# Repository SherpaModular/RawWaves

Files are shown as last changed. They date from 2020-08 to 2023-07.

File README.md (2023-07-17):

## Raw Waves v2

Raw Waves v2 is a sample player that functions much like a live radio. Audio sample files may be placed on a MicroSD card, and arranged into "banks" (like channels) which you may select either manually through the panel knobs, or via CV. File formats supported include RAW and WAV files.

The module is functionally identical to the popular "Raw Waves" module, and its predecessor, "Radio Music" by Tom Whitwell of Music Thing Modular. These previous modules are no longer available, having been built upon the now-discontinued Teensy 3 microcontroller.

Raw Waves v2 has been completely redesigned to use the Teensy 4 platform. Because the module uses the Teensy 4 microcontroller, the "Raw Waves v2" will not be compatible with other alternative firmware made for Radio Music (e.g. 'Chord Organ').

Raw Waves v2 still supports all of the settings in the SETTINGS.TXT file that you came to know and love in the earlier models. If you haven't played with the settings, you really should!

#### Specifications
Audio output: 16-bit audio output, with hardware anti-alias filtering.
Dimensions: 4 hp, 21mm deep.
Power specifications: Requires +12v (at 100 mA) and -12v (at 10 mA). The module features several protections against accidental reverse power connection: First, a keyed 10-pin Eurorack standard connector, second, automatically resetting fuses, and thirdly, protection diodes.
CV Inputs are designed for 0-5v, with reasonable over/undervoltage protection built-in.

#### Compiling the code
My preference is to use Visual Studio Code:
1. Install the Microsoft "Arduino for Visual Studio Code" extension
2. Add the Teensy packages. You can accomplish this in the "Arduino for Visual Studio Code" extension settings by adding the URL https://www.pjrc.com/teensy/package_teensy_index.json to the "Arduino: Additional Urls, Additional URLs for 3rd party packages." setting.
3. The following file contents, placed into the repo under the filename .vscode\arduino.json helps with other details:
```
{
    "sketch": "Software\\RawWavesV2\\RawWavesV2.ino",
    "configuration": "usb=serial,speed=600,opt=o2std,keys=en-us",
    "board": "teensy:avr:teensy40",
    "output": "ArduinoOutput\\RawWavesV2",
    "port": "COM3"
}
```
4. In VS Code, activate the Command Palette (typically by pressing F1), and choose "Ardunio: Verify".
5. If all codes well, the compiled output should appear in the repo directory, under ArduinoOutput\RawWavesV2

#### License  
Raw Waves is Open Hardware. It is a derivate work of ["Radio Music", by Tom Whitwell](https://github.com/TomWhitwell/RadioMusic). 
All hardware and software design in this project is Creative Commons licensed by Jim Mulvey: [CC-BY-SA: Attribution / ShareAlike](https://creativecommons.org/licenses/by-sa/3.0/)
If you use any work in this project, you should credit Tom Whitwell and me, and you must republish any changes you make under the same license.
This license does permit commercial use of these designs, but consider getting in touch before selling anything.
This project includes work from the [Teensy](https://www.pjrc.com/teensy/) project, which is not covered by this license.

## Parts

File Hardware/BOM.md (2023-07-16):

| Designator | Footprint | Quantity | Value |
| --- | --- | --- | --- |
| RV1 | Alpha9mmPot | 1 | B50k |
| LED1,LED2,LED3,LED4,RESET_LED1 | LED_D3.0mm | 5 | 3mm LED, high lumen |
| J3 | YAMAICHI_MICROSD_VERTICAL | 1 | Micro_SD_Card |
| J1,J2,J5,J6 | PJ301M-12_Compact | 4 | Thonkiconn |
| SW1 | Push_E-Switch_KS01Q01 | 1 | SW_DIP_x01 |
| RV2 | Alpha9mmPot | 1 | B50k |
| R2,R3,R4,R5,R10,R14,R15 | R_0603_1608Metric | 7 | 10k, 1% |
| C3,C9,C4 | CP_Elec_4x5.4 | 3 | 10uF, 25v |
| C1,C11,C2,C10,C7,C5 | C_0603_1608Metric | 6 | 100nF, 25v |
| R16,R19,R8,R12,R1,R20 | R_0603_1608Metric | 6 | 100k, 1% |
| R17,R18 | R_0603_1608Metric | 2 | 200k, 1% |
| D8,D7 | D_SOD-323 | 2 | 1N5819 |
| U1 | Teensy4.0 | 1 | Teensy4.0 |
| R13 | R_0603_1608Metric | 1 | 1k, 1% |
| F2,F1 | R_0805_2012Metric | 2 | Polyfuse_Small |
| U2 | SOIC-8_3.9x4.9mm_P1.27mm  | 1 | PT8211 |
| R11 | R_0603_1608Metric | 1 | 120k, 1% |
| U5 | SOIC-8_3.9x4.9mm_P1.27mm  | 1 | MCP6002 |
| R7,R6 | R_0603_1608Metric | 2 | 5.6k, 1% |
| U4 | SOT-223-3_TabPin2 | 1 | LM1117MP-5.0 |
| Q1 | SOT-23 | 1 | MMBT3904 |
| U6 | SOIC-8_3.9x4.9mm_P1.27mm  | 1 | TL072 |
| C8,C6 | C_0603_1608Metric | 2 | 1nF, 25v |
| R9 | R_0603_1608Metric | 1 | 330k, 1% |
| J4 | Eurorack_power_header | 1 | EURO_PWR_2x5 |

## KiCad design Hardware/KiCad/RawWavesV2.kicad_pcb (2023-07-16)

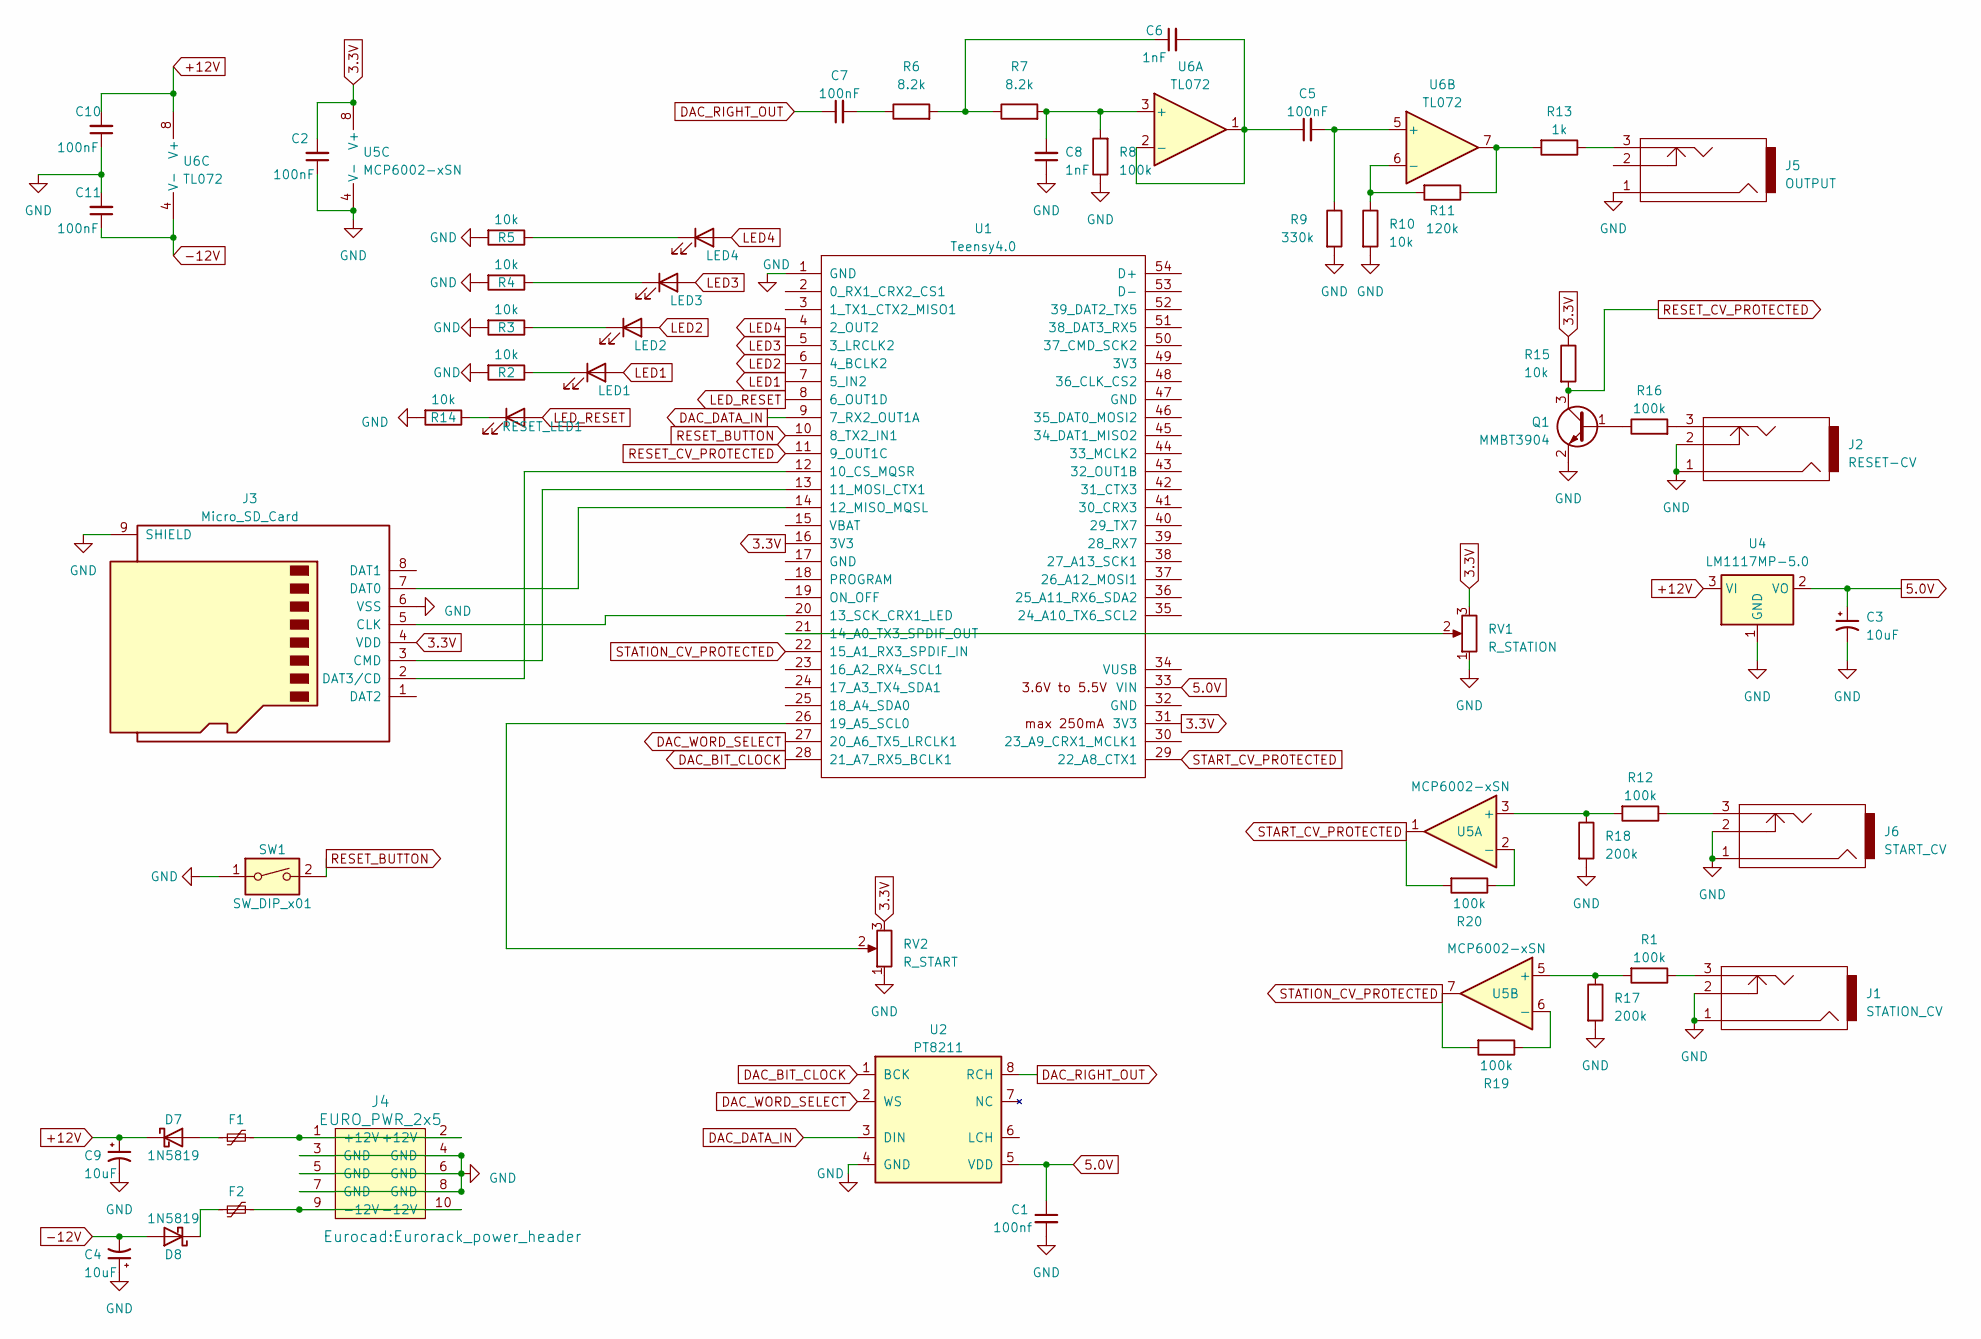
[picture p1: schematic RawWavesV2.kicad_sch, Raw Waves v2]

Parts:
C1: 100nf; C_0603_1608Metric
C2, C5, C7, C10, C11: 100nF; C_0603_1608Metric
C3, C4, C9: 10uF; CP_Elec_4x5.4
C6, C8: 1nF; C_0603_1608Metric
D7, D8: 1N5819; D_SOD-323
F1, F2: Polyfuse_Small; R_0805_2012Metric
J1: STATION_CV; PJ301M-12_Compact
J2: RESET-CV; PJ301M-12_Compact
J3: Micro_SD_Card; YAMAICHI_MICROSD_VERTICAL
J4: EURO_PWR_2x5; Eurorack_power_header
J5: OUTPUT; PJ301M-12_Compact
J6: START_CV; PJ301M-12_Compact
LED1: LED1; LED_D3.0mm
LED2: LED2; LED_D3.0mm
LED3: LED3; LED_D3.0mm
LED4: LED4; LED_D3.0mm
Q1: MMBT3904; SOT-23
R1, R8, R12, R16, R19, R20: 100k; R_0603_1608Metric
R2, R3, R4, R5, R10, R14, R15: 10k; R_0603_1608Metric
R6, R7: 8.2k; R_0603_1608Metric
R9: 330k; R_0603_1608Metric
R11: 120k; R_0603_1608Metric
R13: 1k; R_0603_1608Metric
R17, R18: 200k; R_0603_1608Metric
RESET_LED1: RESET_LED; LED_D3.0mm
RV1: R_STATION; Alpha9mmPot
RV2: R_START; Alpha9mmPot
SW1: SW_DIP_x01; Push_E-Switch_KS01Q01
U1: Teensy4.0; Teensy4.0-RawWavesV2
U2: PT8211; SOIC-8_3.9x4.9mm_P1.27mm
U4: LM1117MP-5.0; SOT-223-3_TabPin2
U5: MCP6002-xSN; SOIC-8_3.9x4.9mm_P1.27mm
U6: TL072; SOIC-8_3.9x4.9mm_P1.27mm

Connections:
3.3V: C2.2, J3.4 (VDD), R15.1, RV1.3, RV2.3, U1.16 (3V3), U1.31 (3V3), U5.8 (V+)
5.0V: C1.1, C3.1, U1.33 (VIN), U2.5 (VDD), U4.2 (VO)
+12V: C9.1, C10.2, D7.1 (K), U4.3 (VI), U6.8 (V+)
-12V: C4.2, C11.1, D8.2 (A), U6.4 (V-)
DAC_BIT_CLOCK: U1.28 (21_A7_RX5_BCLK1), U2.1 (BCK)
DAC_DATA_IN: U1.9 (7_RX2_OUT1A), U2.3 (DIN)
DAC_RIGHT_OUT: C7.1, U2.8 (RCH)
DAC_WORD_SELECT: U1.27 (20_A6_TX5_LRCLK1), U2.2 (WS)
GND: C1.2, C2.1, C3.2, C4.1, C8.1, C9.2, C10.1, C11.2, J1.1, J1.2, J2.1, J2.2, J3.6 (VSS), J3.9 (SHIELD), J4.3 (GND), J4.4 (GND), J4.5 (GND), J4.6 (GND), J4.7 (GND), J4.8 (GND), J5.1, J6.1, J6.2, Q1.2 (E), R2.2, R3.2, R4.2, R5.2, R8.1, R9.2, R10.2, R14.2, R17.2, R18.2, RV1.1, RV2.1, SW1.1, U1.1 (GND), U2.4 (GND), U4.1 (GND), U5.4 (V-)
LED1: LED1.2 (A), U1.7 (5_IN2)
LED2: LED2.2 (A), U1.6 (4_BCLK2)
LED3: LED3.2 (A), U1.5 (3_LRCLK2)
LED4: LED4.2 (A), U1.4 (2_OUT2)
LED_RESET: RESET_LED1.2 (A), U1.8 (6_OUT1D)
unnamed: C6.1, R6.2, R7.1
unnamed: C7.2, R6.1
unnamed: D7.2 (A), F1.1
unnamed: D8.1 (K), F2.1
unnamed: F1.2, J4.1 (+12V), J4.2 (+12V)
unnamed: F2.2, J4.9 (-12V), J4.10 (-12V)
unnamed: J1.3, R1.1
unnamed: J2.3, R16.2
unnamed: J3.5 (CLK), U1.20 (13_SCK_CRX1_LED)
unnamed: J3.3 (CMD), U1.13 (11_MOSI_CTX1)
unnamed: J3.7 (DAT0), U1.14 (12_MISO_MQSL)
unnamed: J3.2 (DAT3/CD), U1.12 (10_CS_MQSR)
unnamed: J5.3, R13.1
unnamed: J6.3, R12.1
unnamed: LED1.1 (K), R2.1
unnamed: LED2.1 (K), R3.1
unnamed: LED3.1 (K), R4.1
unnamed: LED4.1 (K), R5.1
unnamed: Q1.1 (B), R16.1
unnamed: R11.1, R13.2, U6.7
unnamed: R14.1, RESET_LED1.1 (K)
unnamed: RV1.2, U1.21 (14_A0_TX3_SPDIF_OUT)
unnamed: RV2.2, U1.26 (19_A5_SCL0)
unnamed: R12.2, R18.1, U5.3 (+)
unnamed: R20.1, U5.2 (-)
unnamed: R1.2, R17.1, U5.5 (+)
unnamed: R19.1, U5.6 (-)
unnamed: C8.2, R7.2, R8.2, U6.3 (+)
unnamed: C5.1, C6.2, U6.1, U6.2 (-)
unnamed: C5.2, R9.1, U6.5 (+)
unnamed: R10.1, R11.2, U6.6 (-)
RESET_BUTTON: SW1.2, U1.10 (8_TX2_IN1)
RESET_CV_PROTECTED: Q1.3 (C), R15.2, U1.11 (9_OUT1C)
START_CV_PROTECTED: R20.2, U1.29 (22_A8_CTX1), U5.1
STATION_CV_PROTECTED: R19.2, U1.22 (15_A1_RX3_SPDIF_IN), U5.7

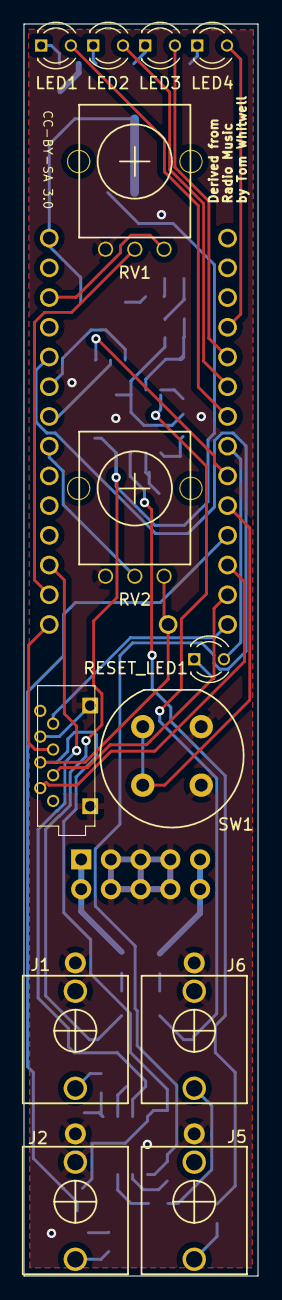
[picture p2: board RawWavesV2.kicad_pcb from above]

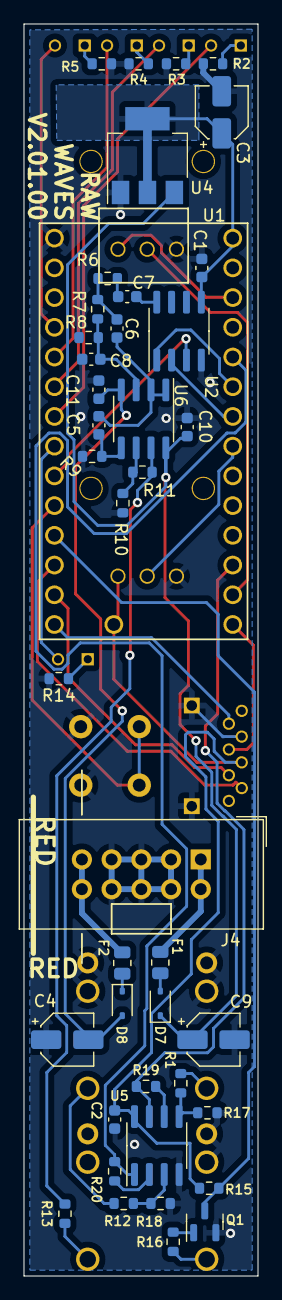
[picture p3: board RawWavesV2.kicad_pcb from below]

Board: 2 copper layers, 20.0 x 107.0 mm, 55 parts (42 on the bottom side), 49 nets.

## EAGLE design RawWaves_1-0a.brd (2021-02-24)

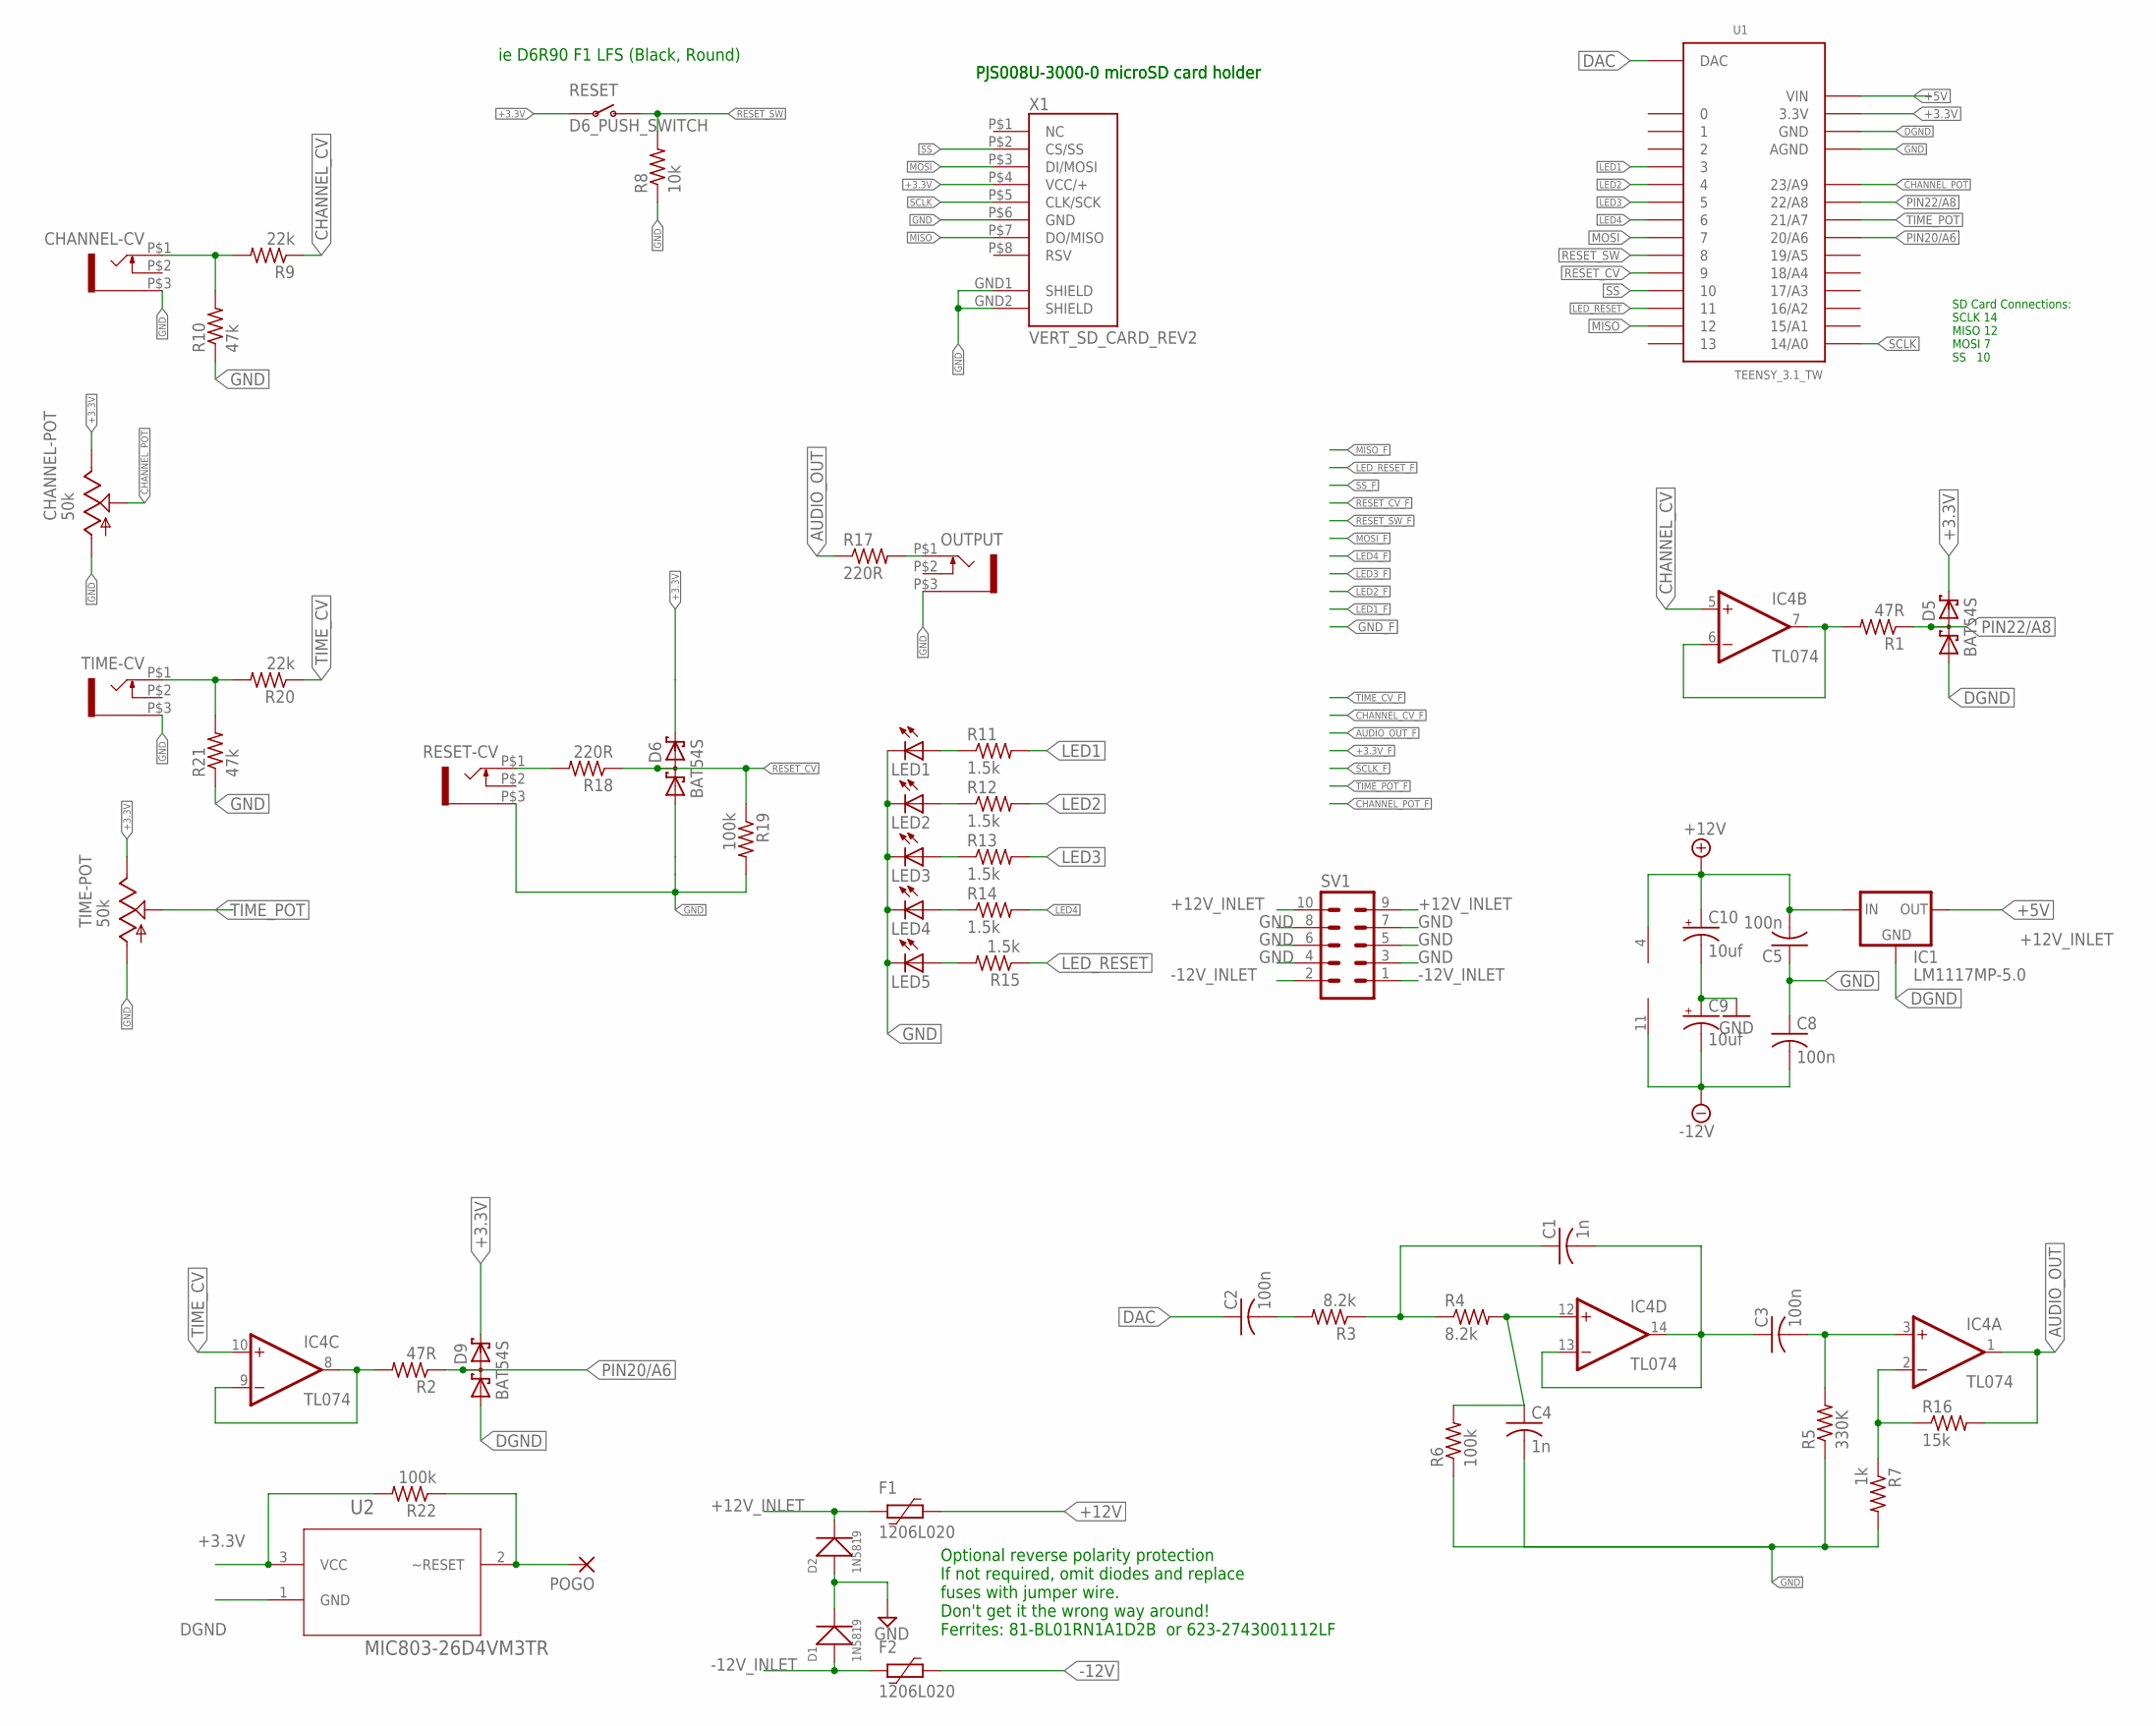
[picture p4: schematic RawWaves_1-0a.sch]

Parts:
C1, C4: 1n; C0805
C2, C3, C5, C8: 100n; C0805
C9, C10: 10uf; PANASONIC_B
CHANNEL-CV: WQP-PJ301M-12_JACK
CHANNEL-POT: 50k; EVUF
D1, D2: 1N5819; SOD-123
D5, D6, D9: BAT54S; SOT23
F1, F2: 1206L020; 1206L
IC1: LM1117MP-5.0; SOT223
IC4: TL074; SO14
LED1, LED2, LED3, LED4, LED5: LED3MM
OUTPUT: WQP-PJ301M-12_JACK
POGO: 1,6/0,8
R1, R2: 47R; R0805
R3, R4: 8.2k; R0805
R5: 330K; R0805
R6, R19, R22: 100k; R0805
R7: 1k; R0805
R8: 10k; R0805
R9, R20: 22k; R0805
R10, R21: 47k; R0805
R11, R12, R13, R14, R15: 1.5k; R0805
R16: 15k; R0805
R17, R18: 220R; R0805
RESET: D6_PUSH_SWITCH; D6_BUTTON_RND
RESET-CV: WQP-PJ301M-12_JACK
SV1: 10_PIN_HEADER; MA05-2
TIME-CV: WQP-PJ301M-12_JACK
TIME-POT: 50k; EVUF
U1: TEENSY_3.1_TW
U2: MIC803-26D4VM3TR; SOT95P232X110-3N
X1: VERT_SD_CARD_REV2; VERT_MICROSD_REV2

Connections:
+3.3V: CHANNEL-POT.3 (E), D5.2 (C2), D6.2 (C2), D9.2 (C2), R22.2, RESET.P$3, RESET.P$4, TIME-POT.3 (E), U1.3.3V, U2.3 (VCC), X1.P$4 (VCC/+)
+5V: IC1.2 (OUT), IC1.4 (OUT), U1.VIN
+12V: C5.2, C10.+, F1.1, IC1.3 (IN), IC4.4 (V+)
+12V_INLET: D2.-, F1.2, SV1.9, SV1.10
-12V: C8.2, C9.-, F2.1, IC4.11 (V-)
-12V_INLET: D1.+, F2.2, SV1.1, SV1.2
AUDIO_OUT: IC4.1 (OUT), R16.2, R17.1
CHANNEL_CV: IC4.5 (+IN), R9.1
CHANNEL_POT: CHANNEL-POT.2 (S), U1.23/A9
DAC: C2.1, U1.DAC
DGND: D5.1 (A1), D9.1 (A1), IC1.1 (GND), U1.GND, U2.1 (GND)
GND: C4.2, C5.1, C8.1, C9.+, C10.-, CHANNEL-CV.P$3 (1), CHANNEL-POT.1 (A), D1.-, D2.+, D6.1 (A1), LED1.K (C), LED2.K (C), LED3.K (C), LED4.K (C), LED5.K (C), OUTPUT.P$3 (1), R5.1, R6.1, R7.2, R8.1, R10.1, R19.2, R21.1, RESET-CV.P$3 (1), SV1.3, SV1.4, SV1.5, SV1.6, SV1.7, SV1.8, TIME-CV.P$3 (1), TIME-POT.1 (A), U1.AGND, X1.GND1 (SHIELD), X1.GND2 (SHIELD), X1.P$6 (GND)
LED1: R11.2, U1.3
LED2: R12.2, U1.4
LED3: R13.2, U1.5
LED4: R14.2, U1.6
LED_RESET: R15.1, U1.11
MISO: U1.12, X1.P$7 (DO/MISO)
MOSI: U1.7, X1.P$3 (DI/MOSI)
unnamed: IC4.6 (-IN), IC4.7 (OUT), R1.2
unnamed: C4.1, IC4.12 (+IN), R4.2, R6.2
unnamed: OUTPUT.P$1 (2), R17.2
unnamed: C1.1, R3.1, R4.1
unnamed: C1.2, C3.1, IC4.13 (-IN), IC4.14 (OUT)
unnamed: C3.2, IC4.3 (+IN), R5.2
unnamed: IC4.2 (-IN), R7.1, R16.1
unnamed: IC4.8 (OUT), IC4.9 (-IN), R2.2
unnamed: CHANNEL-CV.P$1 (2), R9.2, R10.2
unnamed: C2.2, R3.2
unnamed: LED2.A, R12.1
unnamed: LED4.A, R14.1
unnamed: LED3.A, R13.1
unnamed: R18.2, RESET-CV.P$1 (2)
unnamed: LED1.A, R11.1
unnamed: LED5.A, R15.2
unnamed: POGO.1, R22.1, U2.2 (~RESET)
PIN20/A6: D9.3 (C1A2), R2.1, U1.20/A6
PIN22/A8: D5.3 (C1A2), R1.1, U1.22/A8
RESET_CV: D6.3 (C1A2), R18.1, R19.1, U1.9
RESET_SW: R8.2, RESET.P$1 (O), RESET.P$2 (O), U1.8
SCLK: U1.14/A0, X1.P$5 (CLK/SCK)
SS: U1.10, X1.P$2 (CS/SS)
TEMP: R20.2, R21.2, TIME-CV.P$1 (2)
TIME_CV: IC4.10 (+IN), R20.1
TIME_POT: TIME-POT.2 (S), U1.21/A7

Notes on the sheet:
ie D6R90 F1 LFS (Black, Round)
PJS008U-3000-0 microSD card holder
SD Card Connections: SCLK 14 MISO 12 MOSI 7 SS 10
Optional reverse polarity protection If not required, omit diodes and replace fuses with jumper wire. Don't get it the wrong way around! Ferrites: 81-BL01RN1A1D2B or 623-2743001112LF

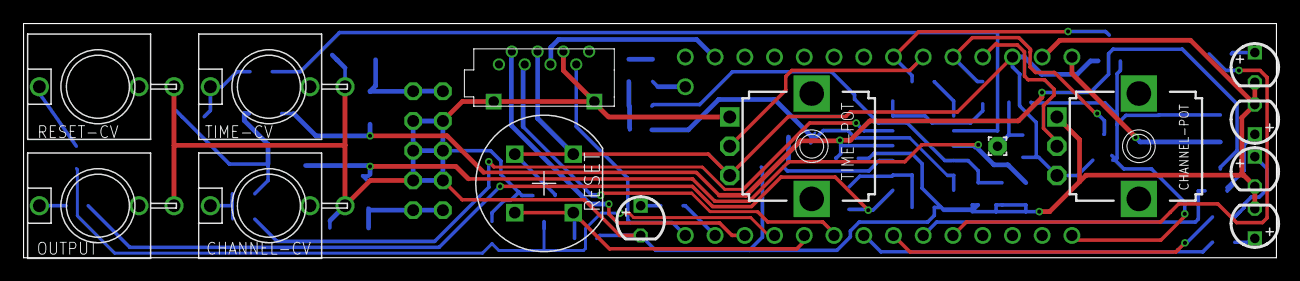
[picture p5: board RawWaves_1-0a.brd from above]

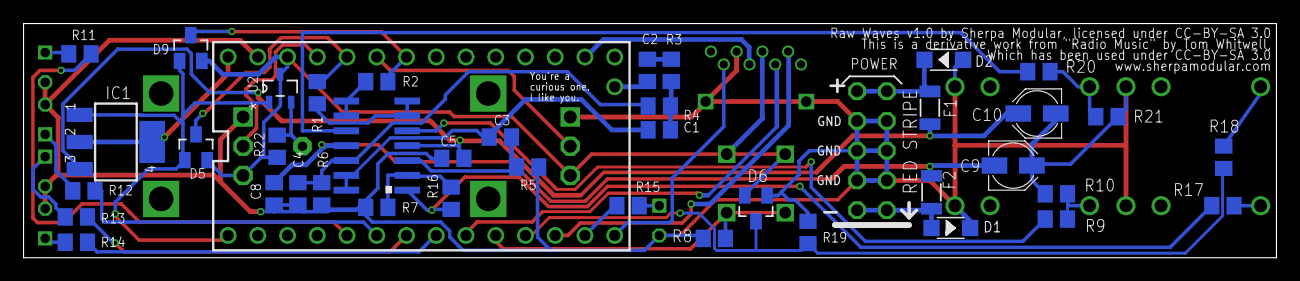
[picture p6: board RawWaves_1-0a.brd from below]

Board: 4 copper layers, 107.0 x 20.0 mm, 56 parts (42 on the bottom side), 45 nets.

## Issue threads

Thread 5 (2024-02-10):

No audio... modified versions of files?

doctea, 2024-02-10:
EDIT AGAIN: after enabling a lot of debug stuff to find out why the play position didn't seem to be updating, etc, and trying out the 'Blank' soundset rather than the other huge sound archives, I notice that amongst the bus noise I'm also hearing very faint bird song when the BIRDS clip is playing, while its powered from USB.  Connecting to eurorack and making sure to play that bank now works OK too.  So seems like I might be having some problems with the sound files in the archive (they seemed to be reporting a large filesize, but 0 length?  not sure).

Seems like probably nothing wrong with the software or hardware anyway, but I'll leave this here in case it helps anyone else when they're trying to find a solution to similar problem: make sure to connect over Eurorack 'cos the audio amplifier won't work when powered only from USB, and make sure the files work!

------

Hi!  Thanks for sharing this project.  I've built one, and it all appears to be working (LEDs light up, respond to knobs being turned and buttons pushed, enabling DEBUG shows files are being detected on the SD card, etc), but I get no sound at the output.  (Well, just bus noise if I turn the gain right up).

I noticed in the RawWavesV2.ino file this comment..

```
 NB: Compile using modified versions of:
 SD.cpp (found in the main Arduino package)
 play_sd_raw.cpp  - In Teensy Audio Library
 play_sc_raw.h    - In Teensy Audio Library
```

..but I couldn't see any modified files with those names in the repository.

Am I missing something about these files?  If necessary, could you please provide steps on what modifications are necessary?

And, could this be the reason I'm not getting any sound output?

Thanks!

EDIT: after a bit more poking around, it seems that this message about the modified versions may just be left over from the original Radio Music source, where it hadn't even been necessary there for quite a while either..?

Any other simple and obvious reasons why I might not be getting any audio output?

Closed 2024-02-11.

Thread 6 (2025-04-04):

'Button' does not name a type

jojo-monk, 2025-04-04:
Hello,

J'ai cette erreur à la compilation : 'Button' does not name a type

jojo-monk, 2025-04-05:
I fixed the bug with:
`Bounce2::Button resetButton;`
Instead of
`Button resetButton;`
in Interface.h

Coombsy87, 2025-07-31:
> I fixed the bug with: `Bounce2::Button resetButton;` Instead of `Button resetButton;` in Interface.h

Thank you for this!! Was doing my head in...

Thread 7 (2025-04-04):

click noise station potentiometer

jojo-monk, 2025-04-04:
When I turn the station potentiometer, we only hear clicks from the beginning until noon, we only hear the samples on the 2nd half of the potentiometer stroke (from 12h until the end).

jojo-monk, 2025-04-05:
Ok, the problem comes from macOS which creates hidden files. The teensy considers them as audio files.

Just delete the hidden files, and everything works.

jmulvey123, 2025-05-16:
Thanks @jojo-monk for creating the issue... and especially for coming back to tell us the cause!
Best, - Jim

Closed 2025-05-16.

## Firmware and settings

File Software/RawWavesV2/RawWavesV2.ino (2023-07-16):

/*
 RAW WAVES v2.0
 https://github.com/SherpaModular/RawWaves
 
 Teensy 4.0
 Audio out: PT8211 external DAC
 
 Bank Button: 2
 Bank LEDs 3,4,5,6
 Reset Button: 8
 Reset LED 2
 Reset CV input: 9
 Channel Pot: A9
 Channel CV: A8 // check
 Time Pot: A7
 Time CV: A6 // check

 SD Card Connections:
 SCK  13
 MISO 12
 MOSI 11
 SS   10
 
 NB: Compile using modified versions of: 
 SD.cpp (found in the main Arduino package) 
 play_sd_raw.cpp  - In Teensy Audio Library 
 play_sc_raw.h    - In Teensy Audio Library 

 */
#include <EEPROM.h>
#include <SPI.h>
#include <SD.h>
//#include <Wire.h>
#include "RawWaves.h"
#include "AudioSystemHelpers.h"
#include "Settings.h"
#include "LedControl.h"
#include "FileScanner.h"
		// which will bring:
		// #include "AudioFileInfo.h"
		// #include "WavHeaderReader.h"
		// #include "Settings.h"
#include "AudioEngine.h"
		// which will bring:
		// #include "SDPlayPCM.h"
		// #include "Settings.h"
#include "Interface.h"
		// which will bring:
		// #include "PlayState.h"
		// #include "Settings.h"
		// #include "AnalogInput.h"
#include "PlayState.h"

#ifdef DEBUG
#define D(x) x
#else
#define D(x)
#endif

#define EEPROM_BANK_SAVE_ADDRESS 0

#define FLASHTIME 	10  	// How long do LEDs flash for?
#define SD_CARD_CHECK_DELAY 20

// //////////
// TIMERS
// //////////

elapsedMillis resetLedTimer = 0;
elapsedMillis ledFlashTimer = 0;

elapsedMillis meterDisplayDelayTimer; // Counter to hide MeterDisplay after bank change
elapsedMillis peakDisplayTimer; // COUNTER FOR PEAK METER FRAMERATE


boolean bankChangeMode = false;
File settingsFile;

Settings settings("SETTINGS.TXT");
LedControl ledControl;
FileScanner fileScanner;
AudioEngine audioEngine;
Interface interface;
PlayState playState;

int NO_FILES = 0;
uint8_t noFilesLedIndex = 0;

uint8_t rebootCounter = 0;

void setup() {

#ifdef DEBUG_STARTUP // Pauses module startup until serial connection is made
	while( !Serial );
	Serial.println("Starting");
#endif // DEBUG_STARTUP

	ledControl.init();
	ledControl.single(playState.bank);

	// SD CARD SETTINGS FOR AUDIO SHIELD
    SPI.setMOSI(11); // pin for MOSI, was 7 in Teensy 3.2 version
    SPI.setSCK(13); // pin for SCK, was 14 in Teensy 3.2 version

	boolean hasSD = openSDCard();
	if(!hasSD) {
		Serial.println("Rebooting");
		reBoot(0);
	}

	settings.init();

	File root = SD.open("/");
	fileScanner.scan(&root, settings);

	getSavedBankPosition();

	audioEngine.init(settings);

	int numFiles = 0;
	for(int i=0;i<=fileScanner.lastBankIndex;i++) {
		numFiles += fileScanner.numFilesInBank[i];
	}
	D(Serial.print("File Count ");Serial.println(numFiles););

	if(numFiles == 0) {
		NO_FILES = 1;
		D(Serial.println("No files"););
		ledFlashTimer = 0;
	} else if(fileScanner.numFilesInBank[playState.bank] == 0) {
		D(Serial.println("Empty bank"););
		while(fileScanner.numFilesInBank[playState.bank] == 0) {
			playState.bank++;
			if(playState.bank == fileScanner.lastBankIndex) {
				playState.bank = 0;
			}
		}
		D(Serial.print("Set bank to ");Serial.println(playState.bank););
	}

	interface.init(fileScanner.fileInfos[playState.bank][0].size, fileScanner.numFilesInBank[playState.bank], settings, &playState);

	D(Serial.println("--READY--"););
}

void getSavedBankPosition() {
	// CHECK FOR SAVED BANK POSITION
	int a = 0;
	a = EEPROM.read(EEPROM_BANK_SAVE_ADDRESS);
	if (a >= 0 && a <= fileScanner.lastBankIndex) {
		D(
			Serial.print("Using bank from EEPROM ");
			Serial.print(a);
			Serial.print(" . Active banks ");
			Serial.println(fileScanner.lastBankIndex);

		);
		playState.bank = a;
		playState.channelChanged = true;
	} else {
		EEPROM.write(EEPROM_BANK_SAVE_ADDRESS, 0);
	};
}

boolean openSDCard() {
	if (!(SD.begin(SS))) { // SS is the SPI chip select pin

		Serial.println("No SD.");
		while (!(SD.begin(SS))) { // SS is the SPI chip select pin
			ledControl.single(15);
			delay(SD_CARD_CHECK_DELAY);
			ledControl.single(rebootCounter % 4); // Modulo 4 on reboot counter. 0,1,2,3,0,1,2,3,0,1,2,3...
			delay(SD_CARD_CHECK_DELAY);
			rebootCounter++;
			Serial.print("Crash Countdown ");
			Serial.println(rebootCounter);
			if (rebootCounter > 4) {
				return false;
			}
		}
	}
	return true;
}

void loop() {

	#ifdef CHECK_CPU
	checkCPU();
//	audioEngine.measure();
	#endif

	if(NO_FILES) {
		// TODO : Flash the lights to show there are no files
		if(ledFlashTimer > 100) {
			ledControl.single(noFilesLedIndex);
			noFilesLedIndex++;
			noFilesLedIndex %= 4;
			ledFlashTimer = 0;
			rebootCounter ++;
			// Wait 3 seconds and reboot
			if(rebootCounter == 30) {
				reBoot(0);
			}
		}
		return;
	}

	updateInterfaceAndDisplay();

	audioEngine.update();

	if(audioEngine.error) {
		// Too many read errors, reboot
		Serial.println("Audio Engine errors. Reboot");
		delay(50); //give a short delay for the serial output to get there
		reBoot(0);
	}

	if (playState.channelChanged) {
		D(
		Serial.print("RW: Going to next channel : ");
		if(playState.channelChanged) Serial.print("RW: Channel Changed. ");
		Serial.println("");
		);

		playState.currentChannel = playState.nextChannel;

		AudioFileInfo* currentFileInfo = &fileScanner.fileInfos[playState.bank][playState.nextChannel];

		audioEngine.changeTo(currentFileInfo, interface.start);
		playState.channelChanged = false;

		resetLedTimer = 0; // This will trigger updateInterfaceAndDisplay(), which is in the main loop, to flash the reset LED

	}

}

void updateInterfaceAndDisplay() {

	checkInterface();

	if (bankChangeMode) {
		ledControl.showReset(1); // Reset LED is on continuously when in bank change mode..
		ledControl.multi(playState.bank);
	} else {
		ledControl.showReset(resetLedTimer < FLASHTIME); // Illuminate the reset LED until the timer runs out
		if (settings.showMeter) {
			peakMeter();
		}
	}
}

// INTERFACE //

void checkInterface() {

	uint16_t changes = interface.update();

	// BANK MODE HANDLING
	if((changes & BUTTON_LONG_PRESS) && !bankChangeMode) {
		D(Serial.println("Enter bank change mode"););
		bankChangeMode = true;
		nextBank();
//		ledFlashTimer = 0;
	} else if((changes & BUTTON_LONG_RELEASE) && bankChangeMode) {
		D(Serial.println("Exit bank change mode"););
		bankChangeMode = false;
	}

	if(changes & BUTTON_PULSE) {
		if(bankChangeMode) {
			D(Serial.println("BUTTON PULSE"););
			nextBank();
		} else {
			D(Serial.println("Button Pulse but not in bank mode"););
		}
	}

	boolean resetTriggered = changes & RESET_TRIGGERED;

	bool skipToStartPoint = false;
	bool speedChange = false;

	if(settings.pitchMode) {

		if(resetTriggered) {
			skipToStartPoint = true;
		}

		if((changes & (ROOT_NOTE_CHANGED | ROOT_POT_CHANGED | ROOT_CV_CHANGED) ) || resetTriggered) {
			speedChange = true;
		}

	} else {

		if((changes & CHANGE_START_NOW) || resetTriggered) {
			skipToStartPoint = true;
		}
	}

	if(resetTriggered) {
		if((changes & CHANNEL_CHANGED) || playState.nextChannel != playState.currentChannel) {
			playState.channelChanged = true;
		} else {
			resetLedTimer = 0; // This will trigger updateInterfaceAndDisplay(), which is in the main loop, to flash the reset LED
		}
	}

	if(speedChange) doSpeedChange();
	if(skipToStartPoint && !playState.channelChanged) {
		if(settings.pitchMode) {
			audioEngine.skipTo(0);
		} else {
			D(Serial.print("Skip to ");Serial.println(interface.start););
			audioEngine.skipTo(interface.start);
		}
	}
}

void doSpeedChange() {
	float speed = 1.0;
	speed = interface.rootNote - settings.rootNote;
	D(Serial.print("Root ");Serial.println(interface.rootNote););
	speed = pow(2,speed / 12); // Raise to power of 2

	audioEngine.setPlaybackSpeed(speed);
}

void nextBank() {

	if(fileScanner.lastBankIndex == 0) { // Only 1 bank. Don't do anything.
		D(Serial.println("Only 1 bank."););
		return;
	}
	playState.bank++;
	if (playState.bank > fileScanner.lastBankIndex) { // If we exceed the last bank, go back to the first bank.
		playState.bank = 0;
	}
	if(fileScanner.numFilesInBank[playState.bank] == 0) { // If the bank is empty, go to the next bank.
		D(Serial.print("No file in bank ");Serial.println(playState.bank););
		nextBank();
	}

	if (playState.nextChannel >= fileScanner.numFilesInBank[playState.bank]) 
		playState.nextChannel = fileScanner.numFilesInBank[playState.bank] - 1;

	interface.setChannelCount(fileScanner.numFilesInBank[playState.bank]);
	playState.channelChanged = true;

	D(
		Serial.print("RW: Next Bank ");
		Serial.println(playState.bank);
	);

	meterDisplayDelayTimer = 0; // Reset the peak meter display delay timer. Once settings.meterHide has elapsed, the peak meter will be displayed again. See peakMeter() below.
	EEPROM.write(EEPROM_BANK_SAVE_ADDRESS, playState.bank);
}

void peakMeter() {
	if( (peakDisplayTimer < 50) || (meterDisplayDelayTimer < settings.meterHide) ) return;

	float peakReading = audioEngine.getPeak();
	int monoPeak = round(peakReading * 4);
	monoPeak = round(pow(2, monoPeak)); // Raise to power of 2. monoPeak = 2^monoPeak. 
	ledControl.multi(monoPeak - 1);
	peakDisplayTimer = 0;
}

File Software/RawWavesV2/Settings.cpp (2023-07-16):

#include <SD.h>
#include "Settings.h"

#include "RawWaves.h"

#ifdef DEBUG_SETTINGS
#define D(x) x
#else
#define D(x)
#endif

Settings::Settings(const char* filename) {
	_filename = filename;
}

void Settings::init() {
	if (!SD.exists(_filename)) {
		write();
	};
	read();
}

void Settings::read() {

	D(Serial.println("Reading settings.txt"););

	char character;
	String settingName;
	String settingValue;
	settingsFile = SD.open("settings.txt");

	uint8_t NAME = 1;
	uint8_t VALUE = 2;
	uint8_t state = NAME;

	if (settingsFile) {
		while (settingsFile.available()) {
			character = settingsFile.read();
			if(state == NAME) {
				if(character == '=') {
					state = VALUE;
				} else {
					settingName = settingName + character;
				}
			} else if(state == VALUE) {
				if(character == '\n') {
					applySetting(settingName, settingValue);
					settingName = "";
					settingValue = "";
					state = NAME;
				} else {
					settingValue = settingValue + character;
				}
			}
		}
		if(settingName.length() > 0 && settingValue.length() > 0) {
			applySetting(settingName, settingValue);
		}
		// close the file:
		settingsFile.close();
	} else {
		// if the file didn't open, print an error:
		Serial.println("error opening settings.txt");
	}
	// Do test settings here

//	crossfade = true;
//	crossfadeTime = 1000;
//	looping = false;
//	anyAudioFiles = true;
//	hardSwap = true;
//	chanPotImmediate = false;
//	chanCVImmediate = false;
//	quantizeNote = true;
//	startCVImmediate = true;
//	startPotImmediate = true;
//	quantiseRootPot = true;
//	quantiseRootCV = true;
//	pitchMode = true;
//	startCVDivider = 1;

#ifdef TEST_RADIO_MODE
	radioMode();
#endif

#ifdef TEST_DRUM_MODE
	drumMode();
#endif

	if(!loopMode) {
		if(pitchMode) {
			loopMode = LOOP_MODE_START_POINT;
		} else {
			loopMode = LOOP_MODE_RADIO;
		}
	}

	D(Serial.print("Loop mode ");Serial.println(loopMode););

	if(anyAudioFiles || pitchMode) {
		hardSwap = true;
	}
}

void Settings::drumMode() {
	crossfade=0;
	crossfadeTime=100;
	showMeter=1;
	meterHide=2000;
	chanPotImmediate=1;
	chanCVImmediate=1;
	startPotImmediate=1;
	startCVImmediate=1;
	startCVDivider=1;
	looping=1;
	sort=1;
	pitchMode=1;
	hardSwap = true;
	anyAudioFiles = true;
	loopMode = LOOP_MODE_START_POINT;
}

void Settings::radioMode() {
	crossfade=1;
	crossfadeTime=100;
	showMeter=1;
	meterHide=2000;
	chanPotImmediate=1;
	chanCVImmediate=1;
	startPotImmediate=0;
	startCVImmediate=0;
	startCVDivider=2;
	looping=1;
	sort=1;
	pitchMode=0;
	hardSwap = false;
	anyAudioFiles = false;
	loopMode = LOOP_MODE_RADIO;
}

// Shamelessly stolen from https://stackoverflow.com/questions/650162/why-cant-the-switch-statement-be-applied-to-strings
constexpr unsigned int hash(const char *s, int off = 0) {                        
    return !s[off] ? 5381 : (hash(s, off+1)*33) ^ s[off];                           
}    

/* Apply the value to the parameter by searching for the parameter name
 Using String.toInt(); for Integers
 toFloat(string); for Float
 toBoolean(string); for Boolean
 */
void Settings::applySetting(String settingName, String settingValue) {
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

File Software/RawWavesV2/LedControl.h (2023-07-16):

#ifndef LedControl_h
#define LedControl_h

/**
 * Raw Waves LED control
 *
 * 4 LEDs across the top and 1 reset LED.
 *
 */
#define LED0 2 // was 6 before PCB change
#define LED1 3 // was 5 before PCB change
#define LED2 4
#define LED3 5 // was 3 before PCB change
#define RESET_LED 6 // Reset LED indicator. Was 11 in Teensy 3.2 but conflicts with the SD card in Teensy 4 // was 2 before PCB change

class LedControl {

	public:
		void init();
		void single(int index);
		void multi(uint8_t bits);
		void showReset(boolean high);

};
#endif

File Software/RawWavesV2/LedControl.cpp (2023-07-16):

#include <Arduino.h>
#include "LedControl.h"

void LedControl::init() {
	pinMode(RESET_LED, OUTPUT);
    pinMode(LED0,OUTPUT);
    pinMode(LED1,OUTPUT);
    pinMode(LED2,OUTPUT);
    pinMode(LED3,OUTPUT);
}

// Set any combination of top row LEDS from the bottom 4 bits
// bit position is the opposite of light position
// e.g. if bottom 4 bits are 0001 the LEDs are * O O O
void LedControl::multi(uint8_t bits) {
    digitalWrite(LED3, HIGH && (bits & 1));
    digitalWrite(LED2, HIGH && (bits & 2));
    digitalWrite(LED1, HIGH && (bits & 4));
    digitalWrite(LED0, HIGH && (bits & 8));
}

// Set a single LED on the top row, others will be unlit
void LedControl::single(int index) {
    digitalWrite(LED3, HIGH && (index==0));
    digitalWrite(LED2, HIGH && (index==1));
    digitalWrite(LED1, HIGH && (index==2));
    digitalWrite(LED0, HIGH && (index==3));
}

void LedControl::showReset(boolean high) {
    digitalWrite(RESET_LED, high ? HIGH : LOW);
}

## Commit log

2021-02-24 Add Voltage Supervisor
    [RawWaves_1-0a.brd, RawWaves_1-0a.sch]
2021-02-24 Widen Pogo Hole
    Replaced "Pogo 1.6/0.8" with "Pogo 1.6/0.9"
    [RawWaves_v1-1.brd, RawWaves_v1-1.sch]
2023-07-02 Remove old v1 files
    [RawWaves_v1-1.brd, RawWaves_v1-1.sch]
2023-07-16 Add final v2 schematic, PCB, BOM and software
    [RawWavesV2.kicad_pcb, RawWavesV2.kicad_sch]
2026-08-16 Add GitHub Actions workflow to compile Teensy 4 firmware
    Compiles Software/RawWavesV2 for teensy:avr:teensy40 using arduino-cli
    via the arduino/compile-sketches action, mirroring the local build config.
2026-08-16 Upload compiled firmware as 14-day artifact
    Switch from arduino/compile-sketches (which discards output) to arduino-cli
    directly with --output-dir, then upload the .hex/.elf via actions/upload-artifact.

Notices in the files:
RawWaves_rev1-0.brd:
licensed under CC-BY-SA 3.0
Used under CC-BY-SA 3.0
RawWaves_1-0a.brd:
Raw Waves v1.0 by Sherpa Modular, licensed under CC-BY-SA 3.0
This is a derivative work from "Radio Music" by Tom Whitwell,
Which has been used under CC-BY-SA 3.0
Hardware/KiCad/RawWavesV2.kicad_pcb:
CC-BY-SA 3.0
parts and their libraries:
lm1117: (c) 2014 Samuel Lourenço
